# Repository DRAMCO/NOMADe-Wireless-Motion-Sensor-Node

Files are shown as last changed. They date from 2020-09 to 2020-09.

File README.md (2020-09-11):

# NOMADe - Wireless Motion Sensor Node
 Documentation about the wireless motion sensor node.

## Software
 This map contains the c/c++ and python code for both the sensor node and receiver.
 
## Hardware
 Here you can find the Eagle schematics and STL files.

## How to cite
```LaTex
@Misc{Interreg-NOMADe,
  author =   {J. Cappelle},
  title =    {{Wireless Motion Sensor Node}},
  howpublished  = {\url{https://github.com/DRAMCO/NOMADe-Wireless-Motion-Sensor-Node}},
  doi = {10.5281/zenodo.4024373}
}
```

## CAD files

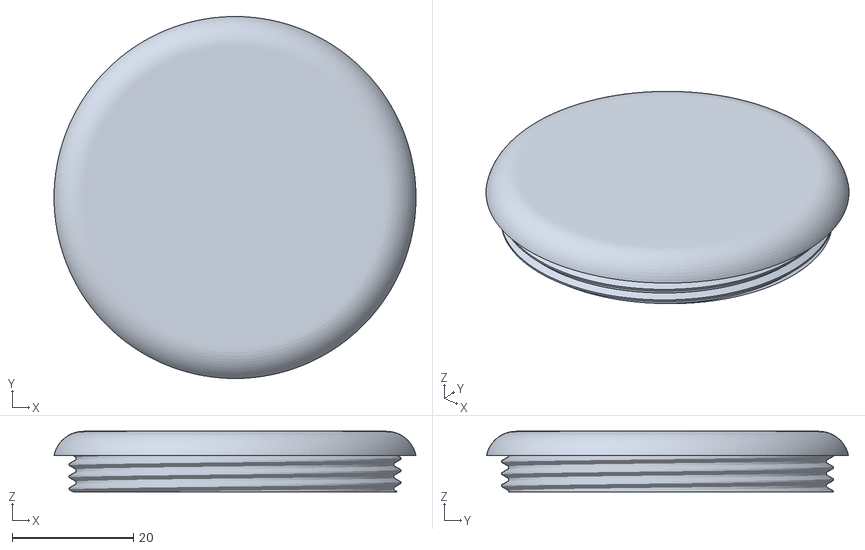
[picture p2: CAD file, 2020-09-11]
Hardware/top.stl
59.8 x 59.8 x 10.0

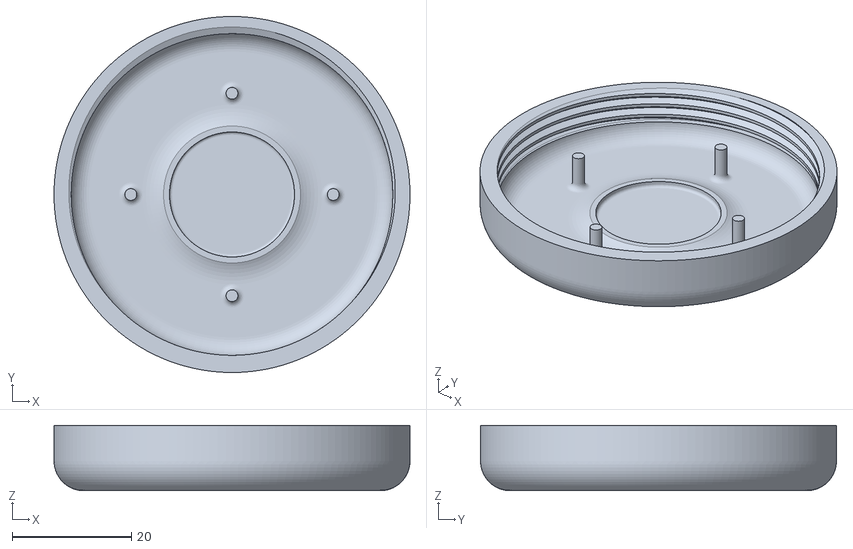
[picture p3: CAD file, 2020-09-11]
Hardware/bottom.stl
59.8 x 59.8 x 11.0

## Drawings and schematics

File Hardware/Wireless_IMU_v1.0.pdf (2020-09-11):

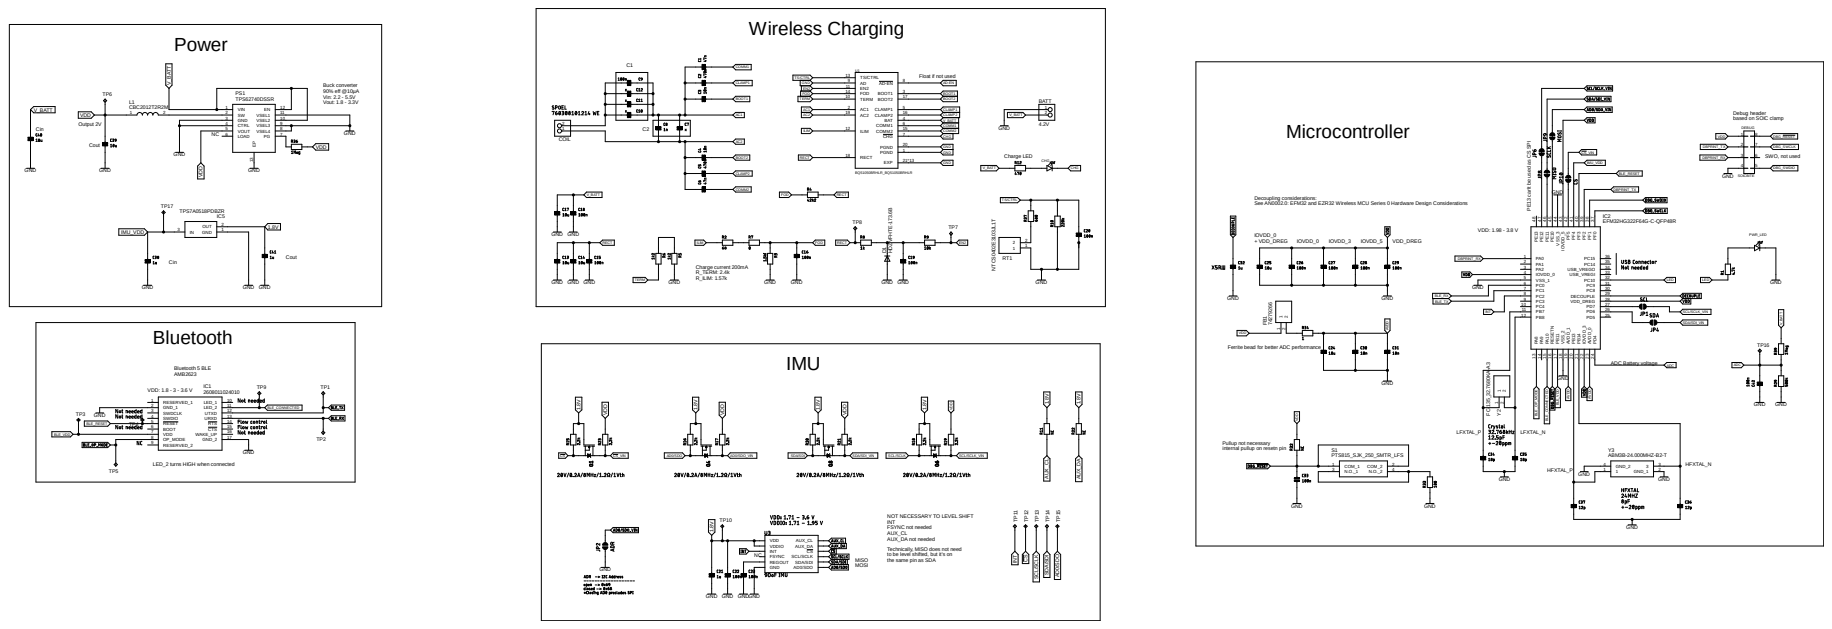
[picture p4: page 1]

Float if not used

Debug header
based on SOIC clamp

Decoupling considerations:
See AN0002.0: EFM32 and EZR32 Wireless MCU Series 0 Hardware Design Considerations

25 PE¹³ ⁴⁸ PE¹² ⁴⁷ PE¹¹ ⁴⁶ PE¹⁰ ⁴⁵ VSS_3 44 IOVDD_5 43 PF5 42 PF4 41 PF3 40 PF2 39 PF1 38 PF0 37

Ferrite bead for better ADC performance

Pullup not necessary
internal pullup on resetn pin

LED_2 turns HIGH when connected

NOT NECESSARY TO LEVEL SHIFT
INT
FSYNC not needed
AUX_CL
AUX_DA not needed
Technically, MISO does not need
to be level shifted, but it's on
the same pin as SDA

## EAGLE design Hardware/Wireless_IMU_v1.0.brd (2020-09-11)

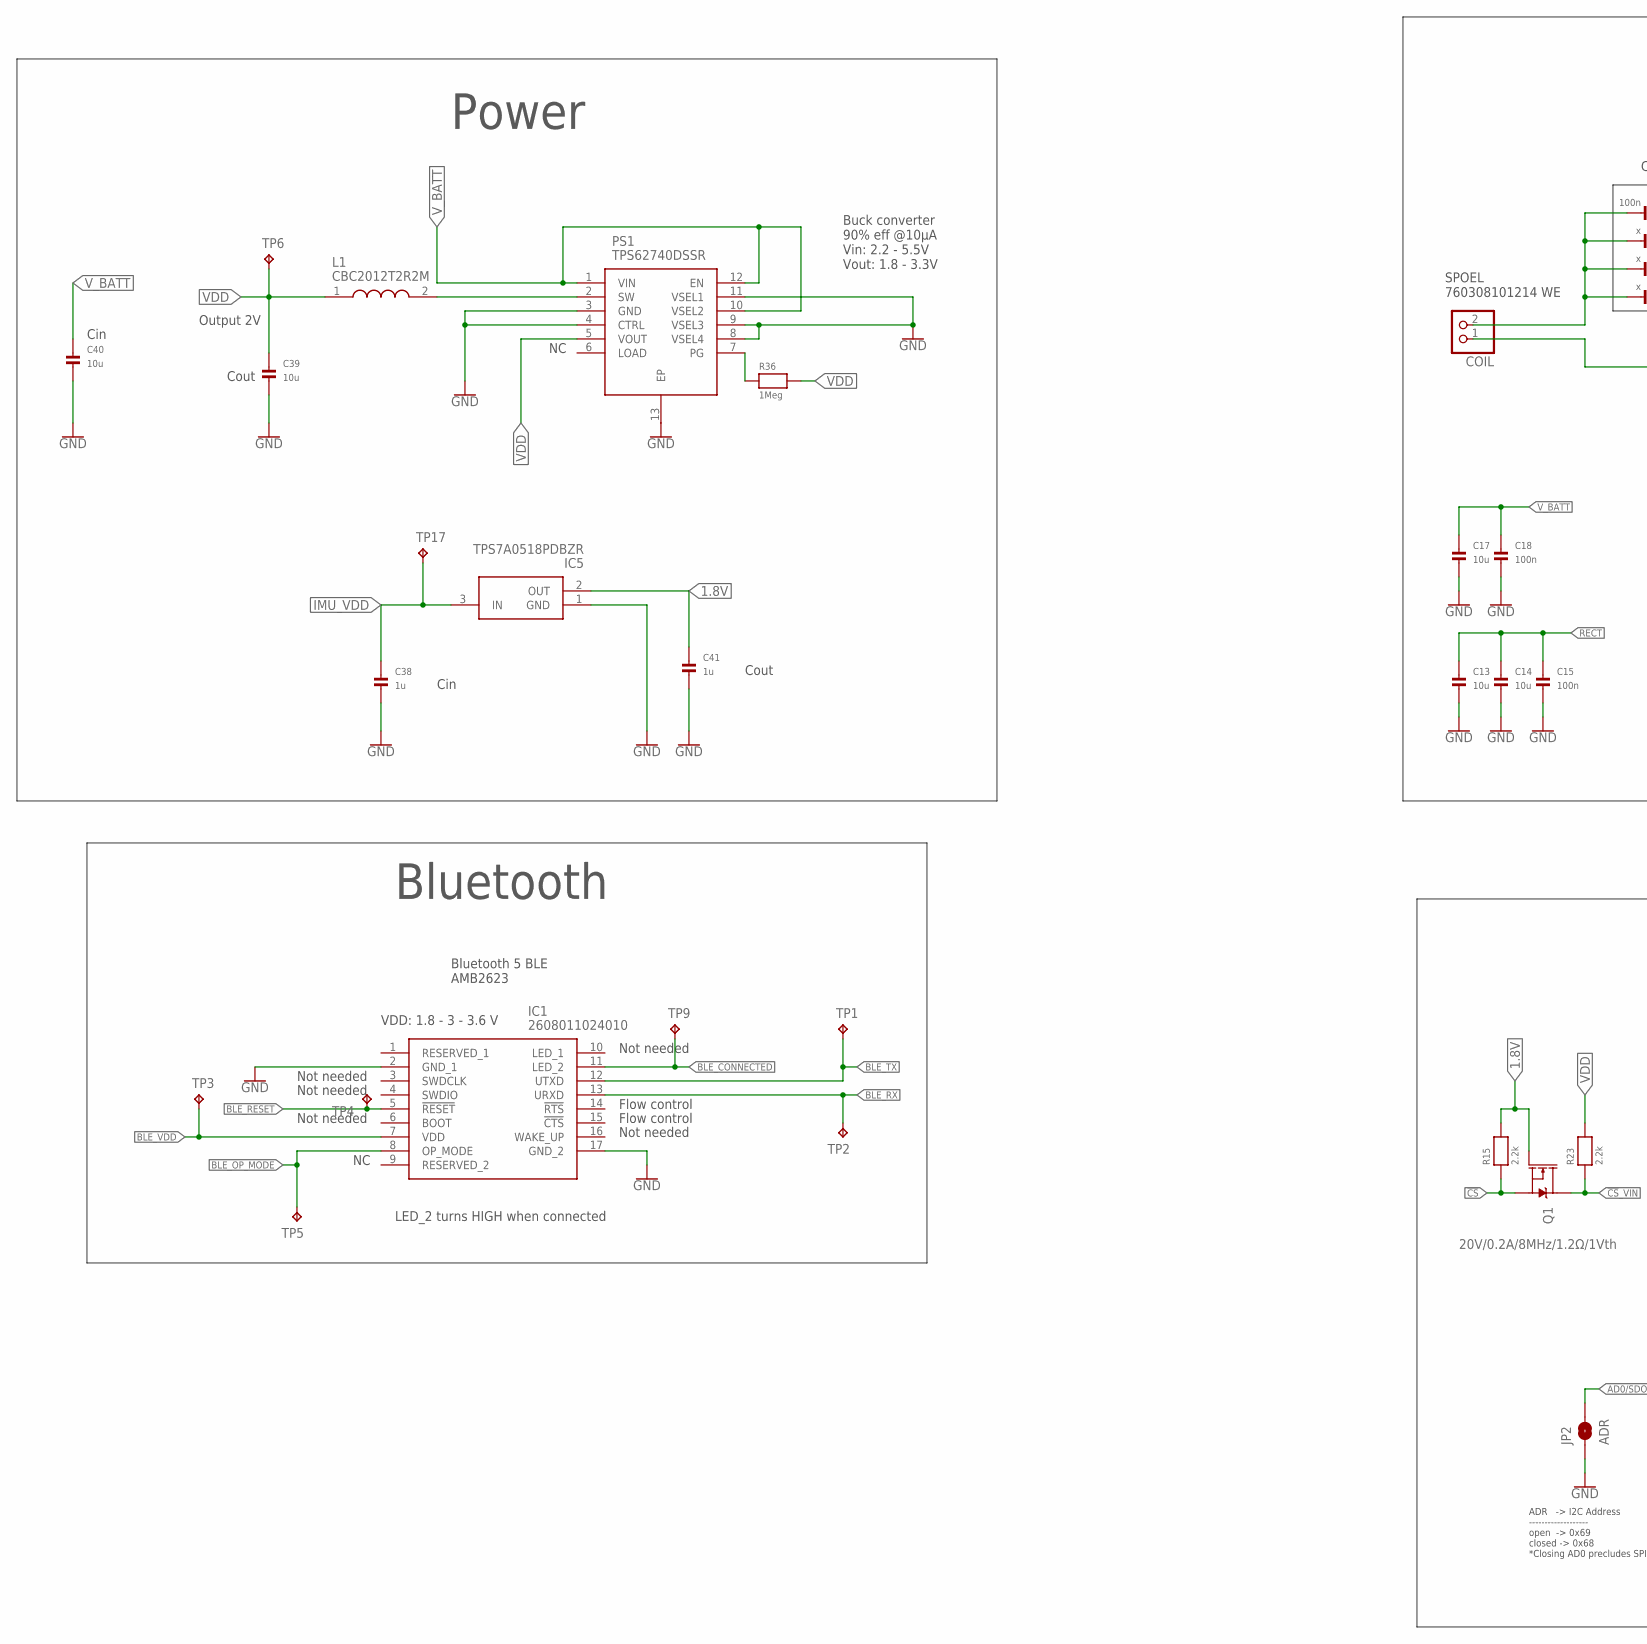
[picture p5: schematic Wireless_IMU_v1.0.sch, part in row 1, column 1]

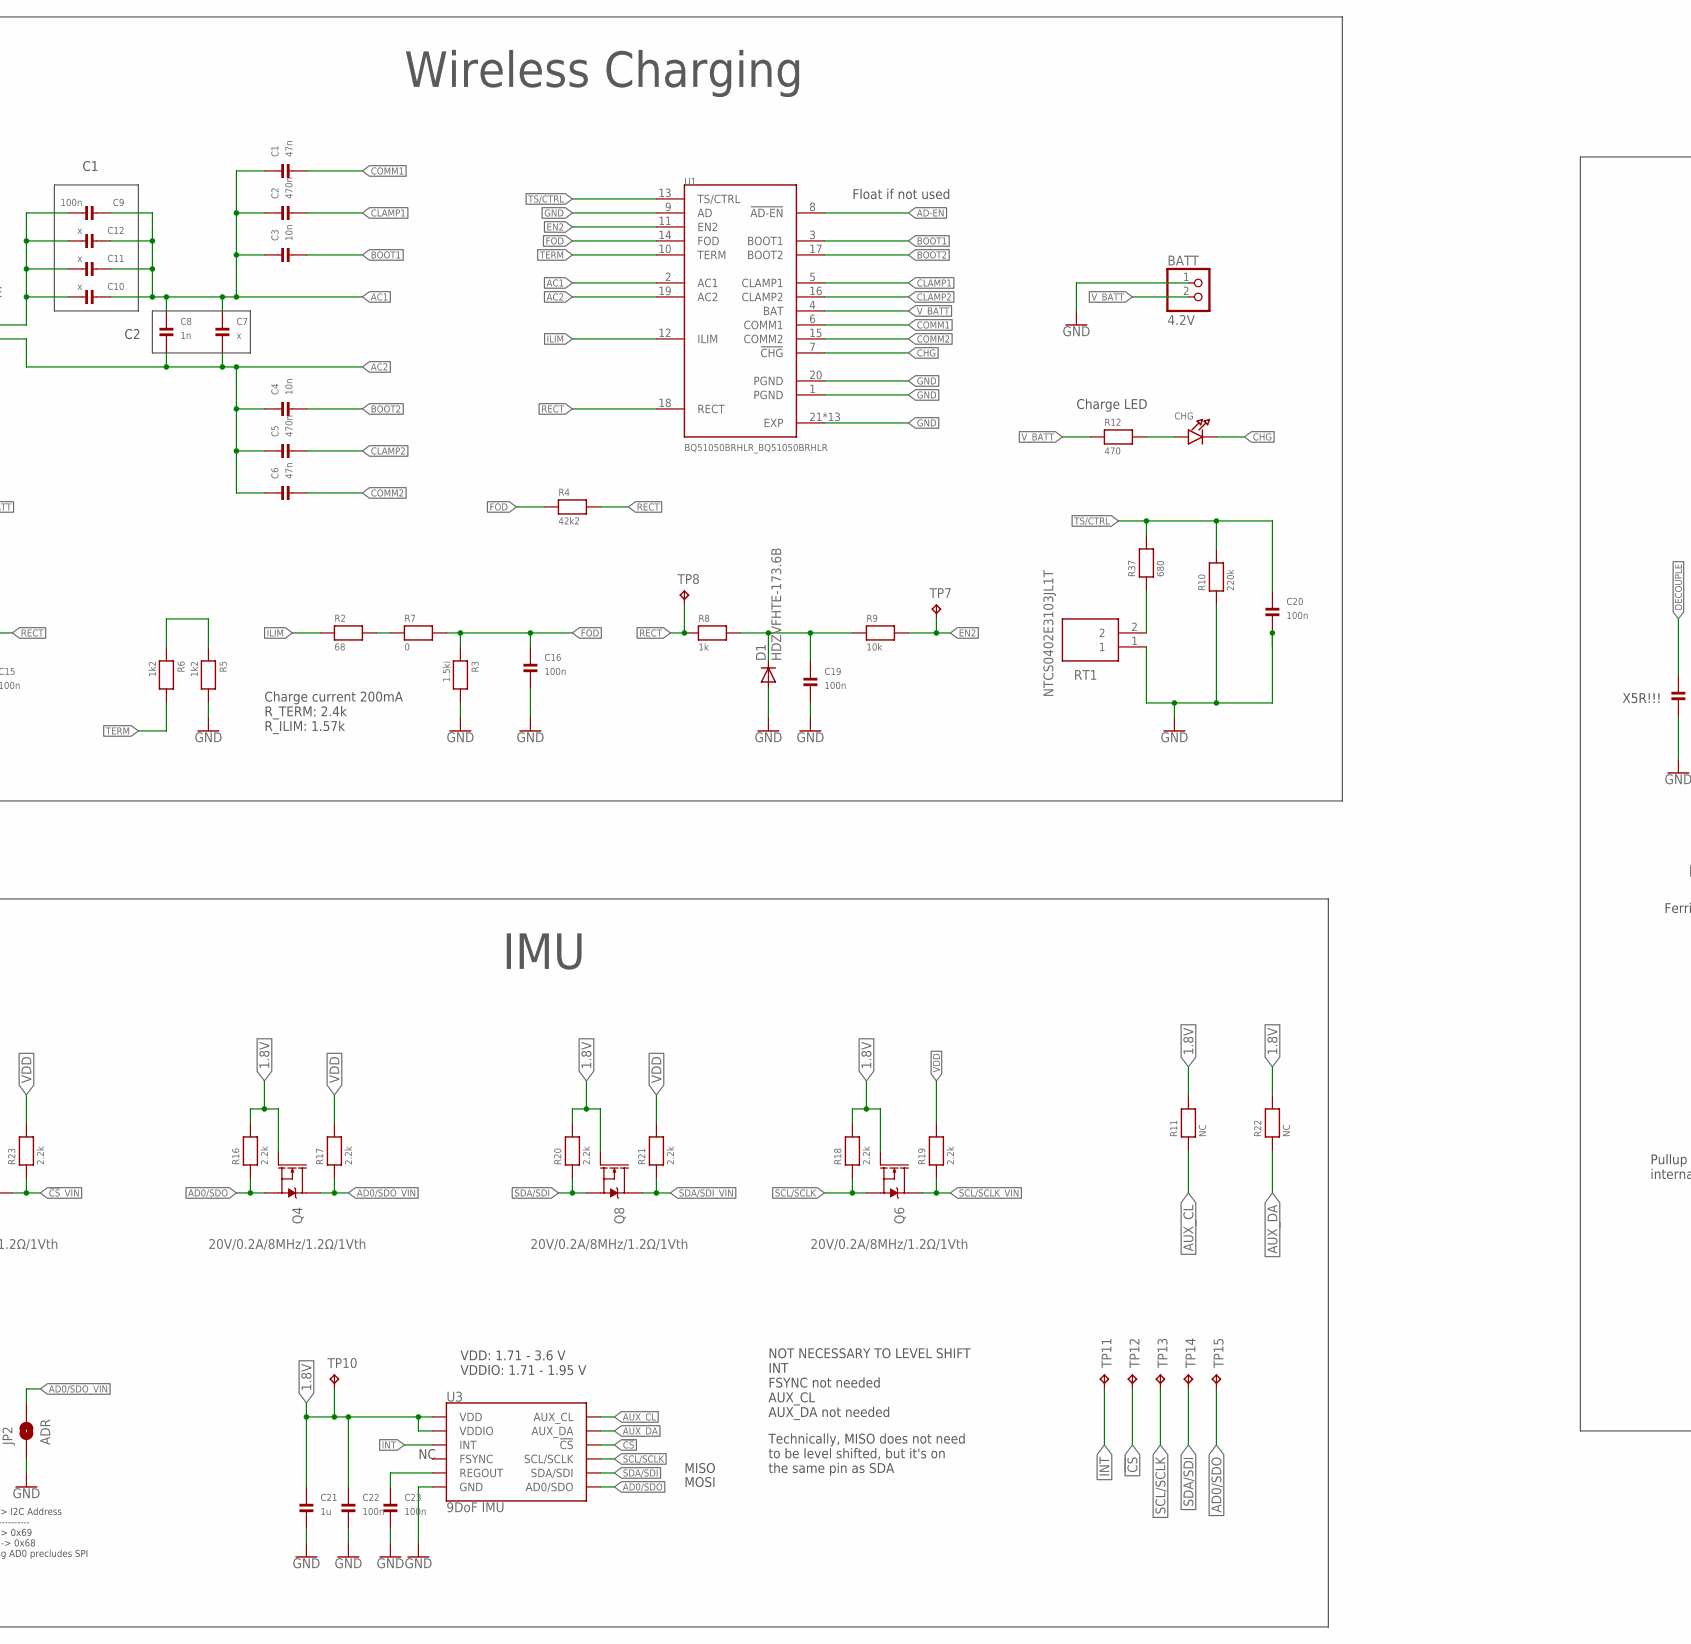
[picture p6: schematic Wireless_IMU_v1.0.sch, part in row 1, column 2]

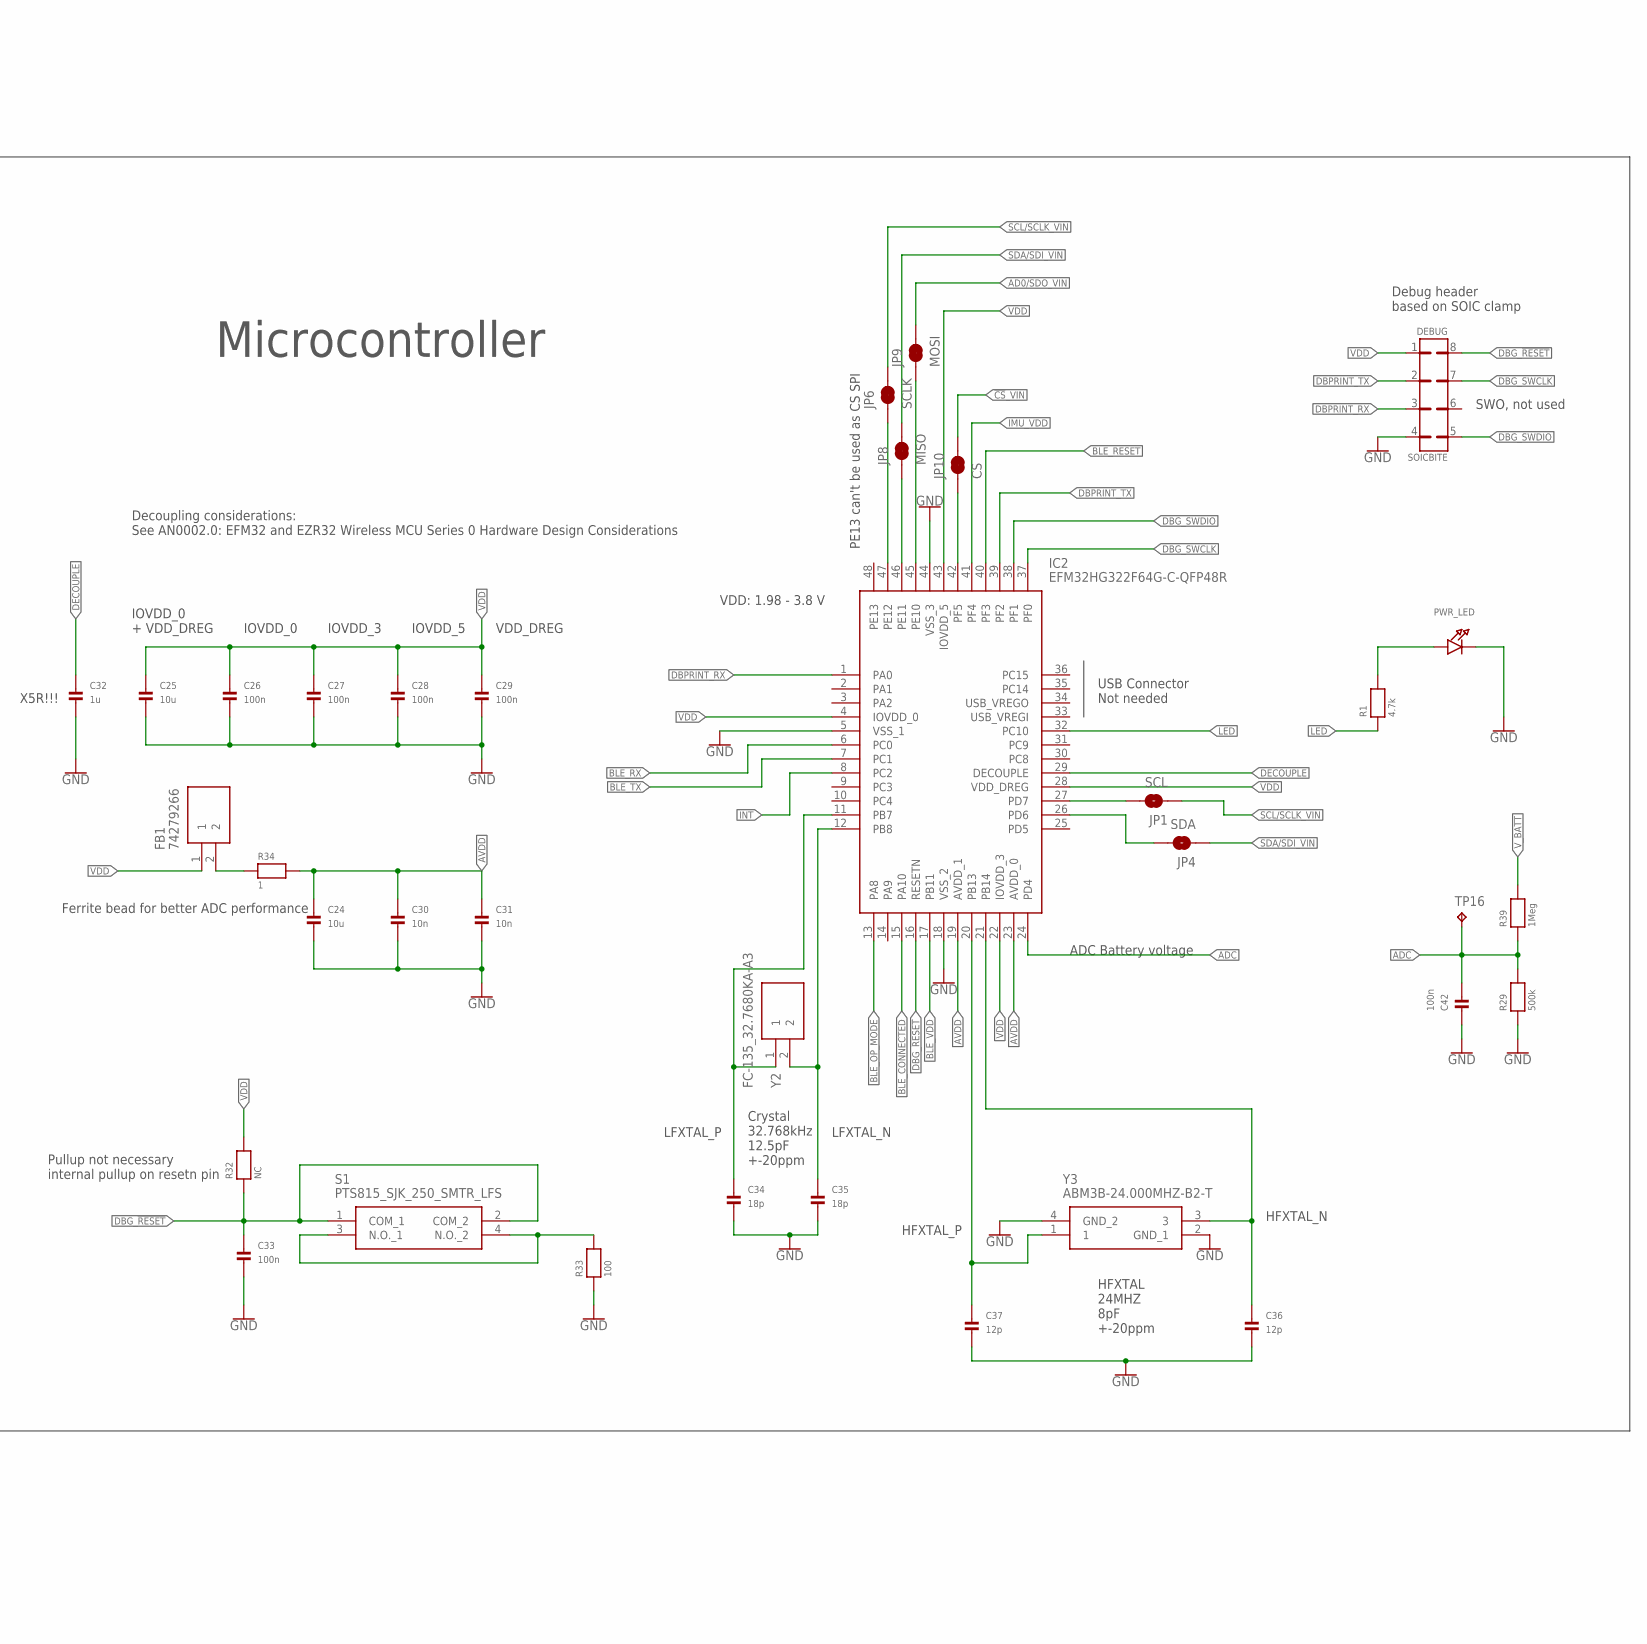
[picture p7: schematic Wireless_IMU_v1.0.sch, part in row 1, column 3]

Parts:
BATT: 4.2V; 1X02
C1, C6: 47n; 0603
C2, C5: 470n; 0603
C3, C4, C30, C31: 10n; 0603
C7, C10, C11, C12: x; 0603
C8: 1n; 0603
C9, C15, C16, C18, C19, C20, C22, C23, C26, C27, C28, C29, C33, C42: 100n; 0603
C13, C14, C17, C24, C25, C39, C40: 10u; 0603
C21, C32, C38, C41: 1u; 0603
C34, C35: 18p; 0603
C36, C37: 12p; 0603
CHG: LED0805; CHIPLED_0805
COIL: PINHD-1X2; 1X02
D1: HDZVFHTE-173.6B; SOD323-W
DEBUG: SOICBITE
FB1: 74279266; BEADC1608X100N
IC1: 2608011024010
IC2: EFM32HG322F64G-C-QFP48R; QFP50P900X900X120-48N
IC5: TPS7A0518PDBZR; SOT95P237X112-3N
JP1: SCL; SMT-JUMPER_2_NO_SILK
JP2: ADR; SMT-JUMPER_2_NO_SILK
JP4: SDA; SMT-JUMPER_2_NO_SILK
JP6: SCLK; SMT-JUMPER_2_NC_TRACE_SILK
JP8: MISO; SMT-JUMPER_2_NC_TRACE_SILK
JP9: MOSI; SMT-JUMPER_2_NC_TRACE_SILK
JP10: CS; SMT-JUMPER_2_NC_TRACE_SILK
L1: CBC2012T2R2M; INDC2012X145N
PS1: TPS62740DSSR; SON50P200X300X80-13N
PWR_LED: LED0805; CHIPLED_0805
Q1, Q4, Q6, Q8: 20V/0.2A/8MHz/1.2Ω/1Vth; SOT-416FL
R1: 4.7k; 0603
R2: 68; 0603
R3: 1.5ki; 0603
R4: 42k2; 0603
R5, R6: 1k2; 0603
R7: 0; 0603
R8: 1k; 0603
R9: 10k; 0603
R10: 220k; 0603
R11, R22, R32: NC; 0603
R12: 470; 0603
R15, R16, R17, R18, R19, R20, R21, R23: 2.2k; 0603
R29: 500k; 0603
R33: 100; 0603
R34: 1; 0603
R36, R39: 1Meg; 0603
R37: 680; 0603
RT1: NTCS0402E3103JL1T; CAPC1005X65N
S1: PTS815_SJK_250_SMTR_LFS; PTS815SJK250SMTRLFS
TP1, TP2, TP3, TP4, TP5, TP6, TP7, TP8, TP9, TP10, TP11, TP12, TP13, TP14, TP15, TP16, TP17: TPTP10R; TP10R
U1: BQ51050BRHLR_BQ51050BRHLR; BQ51050BRHLR_QFN50P450X350X100-21N
U3: 9DoF IMU; SPARKFUN-SENSORS_QFN24-3X3
Y2: FC-135_32.7680KA-A3; FC135327680KAAG0
Y3: ABM3B-24.000MHZ-B2-T; ABM3B8000MHZ101UT

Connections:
1.8V: C21.1, C22.1, C41.1, IC5.2 (OUT), Q1.1 (G), Q4.1 (G), Q6.1 (G), Q8.1 (G), R11.2, R15.2, R16.2, R18.2, R20.2, R22.2, TP10.TP, U3.8 (VDDIO), U3.13 (VDD)
!CS: Q1.2 (S), R15.1, TP12.TP, U3.22 (!CS)
!CS!_VIN: JP10.2, Q1.3 (D), R23.1
AC1: C1.1, C2.1, C3.1, C7.1, C8.1, C9.2, C10.2, C11.2, C12.2, U1.2 (AC1)
AC2: C4.1, C5.1, C6.1, C7.2, C8.2, COIL.1, U1.19 (AC2)
AC11: C9.1, C10.1, C11.1, C12.1, COIL.2
AD0/SDO: Q4.2 (S), R16.1, TP15.TP, U3.9 (AD0/SDO)
AD0/SDO_VIN: JP2.2, JP9.2, Q4.3 (D), R17.1
AD-EN: U1.8 (!AD-EN)
ADC: C42.1, IC2.24 (PD4), R29.2, R39.1, TP16.TP
AUX_CL: R11.1, U3.7 (AUX_CL)
AUX_DA: R22.1, U3.21 (AUX_DA)
AVDD: C24.1, C30.1, C31.1, IC2.19 (AVDD_1), IC2.23 (AVDD_0), R34.2
BLE_CONNECTED: IC1.11 (LED_2), IC2.15 (PA10), TP9.TP
BLE_OP_MODE: IC1.8 (OP_MODE), IC2.13 (PA8), TP5.TP
BLE_RESET: IC1.5 (!RESET), IC2.40 (PF3), TP4.TP
BLE_RX: IC1.13 (URXD), IC2.6 (PC0), TP2.TP
BLE_TX: IC1.12 (UTXD), IC2.7 (PC1), TP1.TP
BLE_VDD: IC1.7 (VDD), IC2.17 (PB11), TP3.TP
BOOT1: C3.2, U1.3 (BOOT1)
BOOT2: C4.2, U1.17 (BOOT2)
CHG: CHG.C, U1.7 (!CHG)
CLAMP1: C2.2, U1.5 (CLAMP1)
CLAMP2: C5.2, U1.16 (CLAMP2)
COMM1: C1.2, U1.6 (COMM1)
COMM2: C6.2, U1.15 (COMM2)
DBG_!RESET: C33.1, DEBUG.8, IC2.16 (RESETN), R32.1, S1.1 (COM_1), S1.2 (COM_2)
DBG_SWCLK: DEBUG.7, IC2.37 (PF0)
DBG_SWDIO: DEBUG.5, IC2.38 (PF1)
DBPRINT_RX: DEBUG.3, IC2.1 (PA0)
DBPRINT_TX: DEBUG.2, IC2.39 (PF2)
DECOUPLE: C32.1, IC2.29 (DECOUPLE)
EN2: R9.2, TP7.TP, U1.11 (EN2)
FOD: C16.1, R3.1, R4.1, R7.2, U1.14 (FOD)
GND: BATT.1, C13.2, C14.2, C15.2, C16.2, C17.2, C18.2, C19.2, C20.2, C21.2, C22.2, C23.2, C24.2, C25.2, C26.2, C27.2, C28.2, C29.2, C30.2, C31.2, C32.2, C33.2, C34.2, C35.2, C36.2, C37.2, C38.2, C39.2, C40.2, C41.2, C42.2, D1.A, DEBUG.4, IC1.2 (GND_1), IC1.17 (GND_2), IC2.5 (VSS_1), IC2.18 (VSS_2), IC2.44 (VSS_3), IC5.1 (GND), JP2.1, PS1.3 (GND), PS1.4 (CTRL), PS1.8 (VSEL4), PS1.9 (VSEL3), PS1.11 (VSEL1), PS1.13 (EP), PWR_LED.C, R3.2, R5.2, R10.1, R29.1, R33.1, RT1.1, U1.1 (PGND), U1.9 (AD), U1.20 (PGND), U1.21 (EXP), U1.22 (EXP), U1.23 (EXP), U1.24 (EXP), U1.25 (EXP), U1.26 (EXP), U1.27 (EXP), U1.28 (EXP), U1.29 (EXP), U1.30 (EXP), U1.31 (EXP), U1.32 (EXP), U1.33 (EXP), U3.18 (GND), U3.20 (GND), Y3.2 (GND_1), Y3.4 (GND_2)
ILIM: R2.1, U1.12 (ILIM)
IMU_VDD: C38.1, IC2.41 (PF4), IC5.3 (IN), TP17.TP
INT: IC2.8 (PC2), TP11.TP, U3.12 (INT)
LED: IC2.32 (PC10), R1.1
unnamed: IC2.27 (PD7), JP1.2
unnamed: R5.1, R6.1
unnamed: PWR_LED.A, R1.2
unnamed: R2.2, R7.1
unnamed: CHG.A, R12.2
unnamed: C19.1, D1.C, R8.2, R9.1
unnamed: IC2.26 (PD6), JP4.2
unnamed: IC2.47 (PE12), JP6.1
unnamed: C35.1, IC2.12 (PB8), Y2.2
unnamed: C23.1, U3.10 (REGOUT)
unnamed: IC2.46 (PE11), JP8.1
unnamed: IC2.45 (PE10), JP9.1
unnamed: C34.1, IC2.11 (PB7), Y2.1
unnamed: IC2.42 (PF5), JP10.1
unnamed: C37.1, IC2.20 (PB13), Y3.1
unnamed: C36.1, IC2.21 (PB14), Y3.3
unnamed: R33.2, S1.3 (N.O._1), S1.4 (N.O._2)
unnamed: FB1.2, R34.1
unnamed: R37.1, RT1.2
unnamed: L1.2, PS1.2 (SW)
unnamed: PS1.7 (PG), R36.1
RECT: C13.1, C14.1, C15.1, R4.2, R8.1, TP8.TP, U1.18 (RECT)
SCL/SCLK: Q6.2 (S), R18.1, TP13.TP, U3.23 (SCL/SCLK)
SCL/SCLK_VIN: JP1.1, JP6.2, Q6.3 (D), R19.1
SDA/SDI: Q8.2 (S), R20.1, TP14.TP, U3.24 (SDA/SDI)
SDA/SDI_VIN: JP4.1, JP8.2, Q8.3 (D), R21.1
TERM: R6.2, U1.10 (TERM)
TS/CTRL: C20.1, R10.2, R37.2, U1.13 (TS/CTRL)
VDD: C25.1, C26.1, C27.1, C28.1, C29.1, C39.1, DEBUG.1, FB1.1, IC2.4 (IOVDD_0), IC2.22 (IOVDD_3), IC2.28 (VDD_DREG), IC2.43 (IOVDD_5), L1.1, PS1.5 (VOUT), R17.2, R19.2, R21.2, R23.2, R32.2, R36.2, TP6.TP
V_BATT: BATT.2, C17.1, C18.1, C40.1, PS1.1 (VIN), PS1.10 (VSEL2), PS1.12 (EN), R12.1, R39.2, U1.4 (BAT)

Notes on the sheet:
Wireless Charging
Bluetooth
IMU
Microcontroller
VDD: 1.8 - 3 - 3.6 V
Bluetooth 5 BLE AMB2623
ADR -> I2C Address ------------------- open -> 0x69 closed -> 0x68 *Closing AD0 precludes SPI
SPOEL 760308101214 WE
VDD: 1.71 - 3.6 V VDDIO: 1.71 - 1.95 V
Not needed
Flow control
USB Connector Not needed
X5R!!!
Crystal 32.768kHz 12.5pF +-20ppm
HFXTAL 24MHZ 8pF +-20ppm
HFXTAL_P
HFXTAL_N
LFXTAL_P
LFXTAL_N
Ferrite bead for better ADC performance
IOVDD_0 + VDD_DREG
IOVDD_0
IOVDD_3
IOVDD_5
Decoupling considerations: See AN0002.0: EFM32 and EZR32 Wireless MCU Series 0 Hardware Design Considerations
Pullup not necessary internal pullup on resetn pin
Debug header based on SOIC clamp
Power
VDD: 1.98 - 3.8 V
Buck converter 90% eff @10µA Vin: 2.2 - 5.5V Vout: 1.8 - 3.3V
Output 2V
Cout
Cin
PE13 can't be used as CS SPI
NOT NECESSARY TO LEVEL SHIFT INT FSYNC not needed AUX_CL AUX_DA not needed
MISO
MOSI
Technically, MISO does not need to be level shifted, but it's on the same pin as SDA
ADC Battery voltage
VDD_DREG

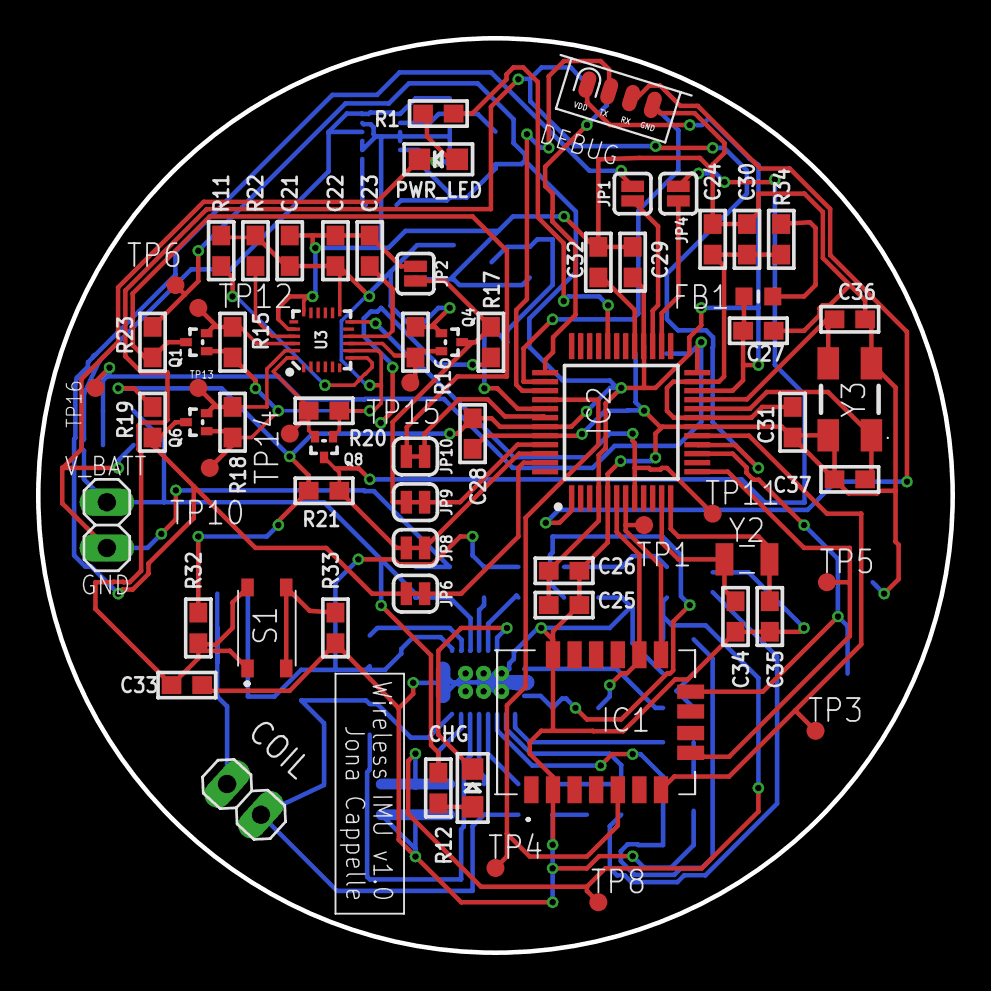
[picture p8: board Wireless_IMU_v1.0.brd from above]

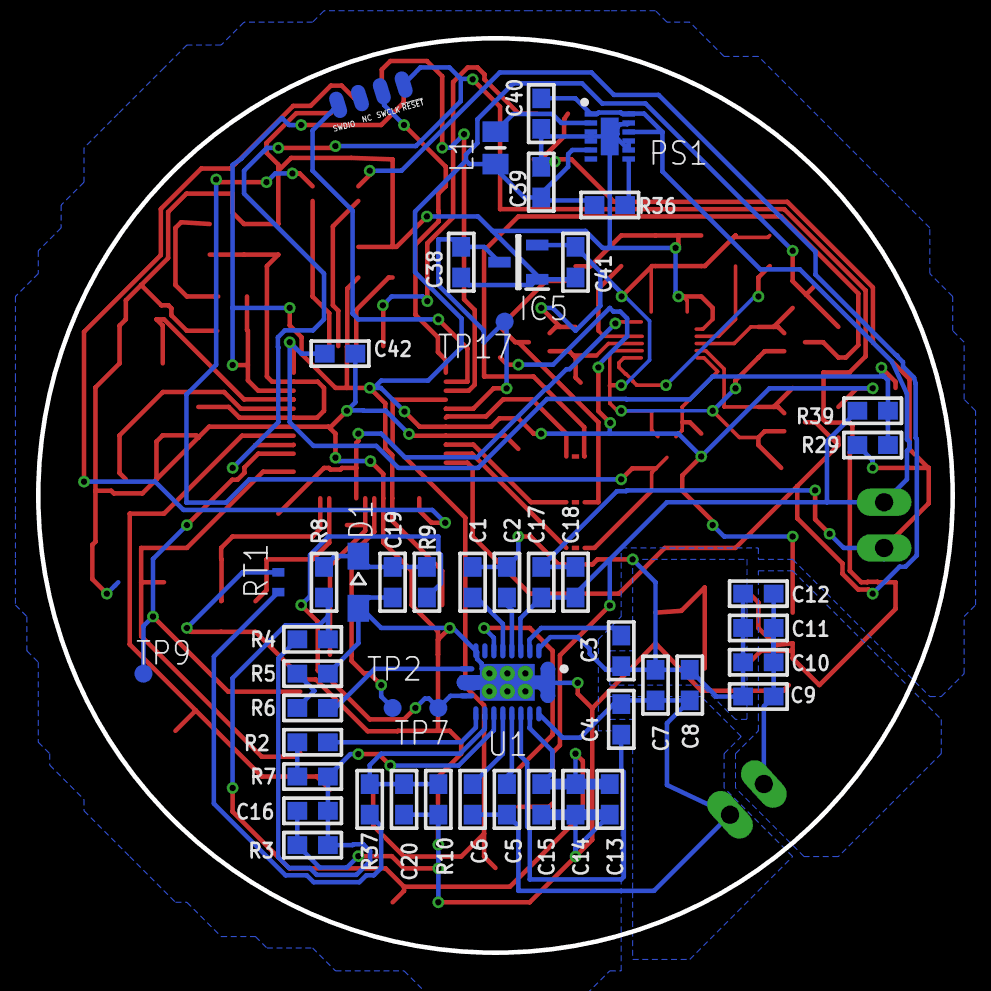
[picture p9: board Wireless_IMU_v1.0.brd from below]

Board: 2 copper layers, 50.8 x 50.8 mm, 116 parts (48 on the bottom side), 68 nets.

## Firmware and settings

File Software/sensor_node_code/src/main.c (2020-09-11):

/* NOMADe Design Sensor Node */
/* Made By Jona Cappelle */

/*************************************************/
/****                                     ********/
/******             MAIN FILE               ******/
/****                                     ********/
/*************************************************/

/***************************************************************************//**
 * @file main.c
 * @brief Code used in master thesis, MAIN FILE
 * @details Development of sensor node to use for threating NMSA
 * @version 1.0
 * @author Jona Cappelle
 * ******************************************************************************
 *
 * @section Versions
 *
 *
 *   @li v1.0: NOMADe wireless sensor node result V1.0
 *
 * ******************************************************************************
 *
 * @todo
 *   **Future improvements:**@n
 *     - Measurement of accuracy of sensor node against reference system
 *     - Enable remote calibration by receiving special packet from BLE
 *
 * ******************************************************************************
 *
 * @section License
 *
 *   **Copyright (C) 2020 - Jona Cappelle**
 *
 *
 ******************************************************************************/










/*
 * Measurement of time
 *
 * uint32_t start = millis();
 * uint32_t duration = millis() - start;
 *
 */

/* Include system libraries */
#include <adc.h>
#include "em_system.h"
#include "em_device.h"
#include "em_chip.h"
#include "em_cmu.h"
#include "em_emu.h"
#include "em_gpio.h"
#include "em_usart.h"
#include "em_rtc.h"
#include "em_adc.h"
//#include "em_wdog.h"
#include "rtcdriver.h"
#include "em_core.h"

/* Include home made libraries */
#include "debug_dbprint.h"
#include "delay.h"
#include "ICM20948.h"
#include "interrupt.h"
#include "ble.h"
#include "uart.h"
#include "timer.h"
#include "datatypes.h"
#include "util.h"

/* Need to make a separate file called "rtcdrv_config.h" and place:
 *
 * #define EMDRV_RTCDRV_WALLCLOCK_CONFIG
 * To enable clock functionality
 // */
#include "rtcdrv_config.h" // voor millis();

/* Separate file for Pins and Constants */
#include "pinout.h"

/* Needed to use uintx_t */
#include <stdint.h>
#include <stdbool.h>
//#include "stdio.h"

/* Communication */
#include "I2C.h"
//#include "em_i2c.h"
//#include "i2cspm.h"				/* I2C higher level library to easily setup and use I2C */

/* Sensor fusion */
#include "MadgwickAHRS.h"
#include "math.h"

/* LED's */
#include "bsp.h"

/* Energy profiles trace code */
#include "bsp_trace.h"

/*************************************************/
/*************************************************/

#define DIY				1							/**< Variable to change between pinout of sensor node and pinout of development board */

/* The use of switch - cases makes the code more user friendly */
static volatile APP_State_t appState;				/**< Struct to keep track of the appState */

/* Keep the measurement data */
MeasurementData_t data;								/**< Struct to store al the measured data and calibration values */

/* bool to check if bluetooth is connected */
bool bleConnected = false;							/**< Keep track of the state of the BLE module */
bool IMU_MEASURING = false;							/**< Keep track of the state of the IMU */
bool IDLE = false;									/**< Variable to keep track if the system is IDLE of the IDLE state, not used at the moment */
bool _sleep = false;								/**< Variable to fix some problems with IMU generating interrupt and thus waking up the system when trying to go to sleep */

uint8_t idle_count = 0;								/**< Seconds that the IMU is idle */
uint8_t ble_sec_not_connected = 0;					/**< 200 ms that the BLE is not connected */

uint32_t interruptStatus[1];						/**< Not used at the moment */

/* Timer for IMU idle checking */
RTCDRV_TimerID_t IMU_Idle_Timer;					/**< Timer used for checking variables every second */

/* Test pin to check frequency of execution */

bool helft = false;									/**< Not used at the moment */

uint8_t teller = 0;									/**< Not used at the moment */
uint8_t teller_accuracy = 0;						/**< Counter to keep track when to enter accuracy mode on Madgwick filter */

volatile float beta = 1.0f;							/**< Beta parameter of Madgwick filter */


/*************************************************/
/*************************************************/

/**************************************************************************//**
 * @brief
 *   Function called by RTC timer every second
 *
 * @details
 *	 Check batt
 *	 Check gyro idle
 *	 Check BLE connected
 *	 Dynamically set Madgwick beta parameter
 *
 *
 *****************************************************************************/
void CheckIMUidle( void )
{

	/* Read battery in percent */
	ADC_get_batt(data.batt);

	float mean_gyro = (uint8_t) ( data.ICM_20948_gyro[0] + data.ICM_20948_gyro[1] + data.ICM_20948_gyro[2] ) / 3;

	/* Add 1 sec to the count of idle seconds */
	if( mean_gyro < 0.1 )
	{
		idle_count++;
	}else{ /* If there is movement, reset idle seconds */
		idle_count = 0;
	}


	if( (idle_count > 60) || (ble_sec_not_connected > 5*5)) // 5sec * 75Hz
	{
		idle_count = 0;
		ble_sec_not_connected = 0;
		teller_accuracy = 0;
		beta = 1.0f;
		/* Dont't check idle state in sleep */
		RTCDRV_StopTimer( IMU_Idle_Timer );
		/* Stop generating interrupts */
		ICM_20948_interruptEnable(false, false);
		appState = SLEEP;
		_sleep = true;
	}
	// Reset timer is BLE is connected
	if(bleConnected)
	{
		ble_sec_not_connected = 0;
	}

/* For visual representation where in the code */
#if DIY == 0
	BSP_LedToggle(1);
#endif

	if(teller_accuracy < 10)
	{
		teller_accuracy++;
	}

	if(teller_accuracy >= 10)
	{
		beta = 0.05f;
	}

}

/**************************************************************************//**
 * @brief
 *   Function called by interrupt from IMU @50 Hz
 *
 * @details
 *	 Measure Gyro + Accel + Magn
 *	 Sensor fusion with Madgwick filter
 *	 Convert quaternions to Euler angles
 *	 Convert floats to uint8_t for transmission
 *	 Send data via UART to BLE module (interrupt based)
 *	 Toggle pin to check speed
 *
 * @note
 * 	 Max execution speed 75 Hz
 *
 *
 *
 *****************************************************************************/
void measure_send( void )
{

	/* Check connection */
#if DEBUG_DBPRINT == 0 /* DEBUG_DBPRINT */
	BLE_check_connect();
	if (!bleConnected)
	{
		ble_sec_not_connected++;
		BLE_power(true);
		delay(200);
		BLE_connect();
	}

#endif /* DEBUG_DBPRINT */

	/* Read all sensors */
	ICM_20948_gyroDataRead(data.ICM_20948_gyro);
	ICM_20948_accelDataRead(data.ICM_20948_accel);
	ICM_20948_magDataRead(data.ICM_20948_magn);

	// TODO: embedded ICM_20948_magn_to_angle( ICM_20948_magn, ICM_20948_magn_angle );

//	uint32_t start = millis();

	/* Sensor fusion */
	MadgwickAHRSupdate(data.ICM_20948_gyro[0] * M_PI / 180.0f,
			data.ICM_20948_gyro[1] * M_PI / 180.0f,
			data.ICM_20948_gyro[2] * M_PI / 180.0f,
			data.ICM_20948_accel[0], data.ICM_20948_accel[1],
			data.ICM_20948_accel[2], data.ICM_20948_magn[0], data.ICM_20948_magn[1], data.ICM_20948_magn[2]);
	QuaternionsToEulerAngles(data.ICM_20948_euler_angles);



//	uint32_t duration = millis() - start;

	/* Convert float's to uint8_t arrays for transmission over BLE */
	float_to_uint8_t_x3(data.ICM_20948_euler_angles,
			data.BLE_euler_angles);

//	helft = !helft;


#if DEBUG_DBPRINT == 0 /* DEBUG_DBPRINT */
//	if(helft == 1)
//	{

//	if(teller < 3)
//	{
	BLE_sendData(data.BLE_euler_angles, data.batt, 13, data.BLE_data);
	/* Test frequency */
	GPIO_PinOutSet(gpioPortE, 11);
	GPIO_PinOutClear(gpioPortE, 11);
//	}else{
//		teller = 0;
//	}
//	teller++;


//	}
#endif /* DEBUG_DBPRINT */

#if DIY == 0
	BSP_LedToggle(0);
#endif


}


/**************************************************************************//**
 * @brief
 *   Main function
 *
 * @details
 *	State diagram
 *	BATT_READ and CALLIBRATE will never be reached
 *	Future update: calibrate when receiving special BLE packet
 *
 *
 *****************************************************************************/
int main(void)
{

	/* Start with initialization */
	appState = INIT;

	/* Infinite loop */
	while (1)
	{
		switch (appState)
		{
		/***************************/
		case SYS_IDLE:
		{
			/* Wait in EM2 */
//			EMU_EnterEM2(true);

		}
			break;
		/***************************/
		case INIT:
		{
			/* Chip errata */
			CHIP_Init();


			/* ENABLE CODE CORRELATION --  uses SWO */
			/* If first word of user data page is non-zero, enable eA Profiler trace */
//			BSP_TraceProfilerSetup();

			/* FULL SPEED */
			CMU_ClockSelectSet(cmuClock_HF, cmuSelect_HFXO);
//			CMU_OscillatorEnable(cmuOsc_HFRCO, false, false);

			CMU_ClockEnable(cmuClock_HFPER, true);
			CMU_ClockEnable(cmuClock_GPIO, true);

			/* Set output pin to check frequency of execution */

			GPIO_PinModeSet(gpioPortE, 11, gpioModePushPull, 0);

#if DIY == 1
			GPIO_PinModeSet(LED_PORT, LED_PIN, gpioModePushPull, 1);
			delay(1000);
			GPIO_PinModeSet(LED_PORT, LED_PIN, gpioModeDisabled, 0);

			blink(3);
#endif

			/* Leds on development board */
#if DIY == 0
			BSP_LedsInit();
#endif

			/* Setup printing to virtual COM port, w */
#if DEBUG_DBPRINT == 1 /* DEBUG_DBPRINT */
			dbprint_INIT(USART1, 4, true, false);
#endif /* DEBUG_DBPRINT */

			/* Timer init */
			RTCDRV_Init();
			RTCDRV_AllocateTimer(&IMU_Idle_Timer);


			/* Initialize ICM_20948 + SPI interface */
			ICM_20948_Init();
			//ICM_20948_Init_SPI();

			/* Initialize GPIO interrupts on port C 2 */
			initGPIO_interrupt();

			/* Initialize ADC to read battery voltage */
			initADC();
//			ADC_get_batt(data.batt);



#if DEBUG_DBPRINT == 1 /* DEBUG_DBPRINT */
			dbprintln("INIT");
#endif /* DEBUG_DBPRINT */

			/* Bluetooth */
#if DEBUG_DBPRINT == 0 /* DEBUG_DBPRINT */
			BLE_Init();
#endif /* DEBUG_DBPRINT */

			delay(200);
			/* Set output power */
//			BLE_set_output_power(BLE_OUTPUT_POWER_0DB);
//			delay(100);

			// TODO Temporary
			/* Check connection */
#if DEBUG_DBPRINT == 0 /* DEBUG_DBPRINT */
			BLE_check_connect();
			if (!bleConnected)
			{
				BLE_power(true);
				delay(1000);
				BLE_connect();
			}
#endif /* DEBUG_DBPRINT */

			/* Set interrupt to trigger every 100ms when the data is ready */
			IMU_MEASURING = true;
			ICM_20948_interruptEnable(true, false);

			/* Fancy LED's */
#if DIY == 0
			for(uint8_t i=0; i<8; i++)
			{
				BSP_LedSet(0);
				BSP_LedSet(1);
				delay(100);
				BSP_LedClear(0);
				BSP_LedClear(1);
				delay(100);
			}
#endif

			/* Timer for checking if IMU is idle */
			  RTCDRV_StartTimer( IMU_Idle_Timer, rtcdrvTimerTypePeriodic, 2000, (RTCDRV_Callback_t)CheckIMUidle, NULL);



			appState = SYS_IDLE;


		}
			break;
			/***************************/
		case SENSORS_READ:
		{

#if DEBUG_DBPRINTs == 1 /* DEBUG_DBPRINT */
			dbprintln("SENSORS_READ");
#endif /* DEBUG_DBPRINT */

			measure_send();

#if DEBUG_DBPRINTs == 1 /* DEBUG_DBPRINT */
			dbprintInt((int) ( data.ICM_20948_gyro[0]*100) );
			dbprint(",");
			dbprintInt((int) (data.ICM_20948_gyro[1] *100) );
			dbprint(",");
			dbprintInt((int) (data.ICM_20948_gyro[2] *100) );
			dbprint(",");
			dbprintInt((int) ( data.ICM_20948_accel[0]*100) );
			dbprint(",");
			dbprintInt((int) (data.ICM_20948_accel[1] *100) );
			dbprint(",");
			dbprintlnInt((int) (data.ICM_20948_accel[2] *100) );
#endif /* DEBUG_DBPRINT */

#if DEBUG_DBPRINTs == 1 /* DEBUG_DBPRINT */
			//dbprint("	roll: ");
			dbprintInt((int) (ICM_20948_euler_angles[0] *100) );
			//dbprint("	pitch: ");
			dbprint("\t");
			dbprintInt((int) (ICM_20948_euler_angles[1] *100) );
			//dbprint("	yaw: ");
			dbprint("\t");
			dbprintlnInt((int) (ICM_20948_euler_angles[2] *100) );
#endif /* DEBUG_DBPRINT */

#if DEBUG_DBPRINTs == 1 /* DEBUG_DBPRINT */
			dbprintInt((int) ICM_20948_magn[0] );
			dbprint(",");
			dbprintInt((int) ICM_20948_magn[1] );
			dbprint(",");
			dbprintlnInt((int) ICM_20948_magn[2] );
#endif /* DEBUG_DBPRINT */


			/* If imu is idle, give it the chance to go to sleep */
			if(!_sleep)
			{
				appState = SYS_IDLE;
			}
		}
			break;
			/***************************/
		case BATT_READ:
		{
			ADC_Batt_Read();
			ADC_get_batt(data.batt);

#if DEBUG_DBPRINT == 1 /* DEBUG_DBPRINT */
			dbprintln("BATT_READ");
#endif /* DEBUG_DBPRINT */

			appState = SYS_IDLE;
		}
			break;
			/***************************/
		case SLEEP:
		{
			//RTCDRV_StartTimer( IMU_Idle_Timer, rtcdrvTimerTypeOneshot, 2000, test, NULL);

			RTCDRV_StopTimer( IMU_Idle_Timer );
			RTCDRV_DeInit();

			BLE_disconnect();
			delay(100);
			BLE_power( false);
			BLE_rxtx_enable( false );

			bleConnected = false;

			CMU_ClockEnable(cmuClock_ADC0, false);
//			GPIO_PinModeSet(gpioPortD, 4, gpioModeDisabled, 0);

			GPIO_PinModeSet(gpioPortE, 11, gpioModeDisabled, 0);


			/* Shut down magnetometer */
		    ICM_20948_set_mag_mode(AK09916_BIT_MODE_POWER_DOWN);
		    delay(100);

		    uint8_t temp1[8];
			ICM_20948_read_mag_register(0x31, 1, temp1);
			/* Update data by reading through till ST2 register */
			ICM_20948_read_mag_register(0x11, 8, temp1);


			/* Wake on motion: 50 mg's (0.05 G) */
			ICM_20948_wakeOnMotionITEnable(true, 20, 2.2);
//			ICM_20948_sleepModeEnable(true);
			delay(400);

			IIC_Enable(false);


			/* Disable Systicks before going to sleep */
			EMU_EnterEM2(true);


			///////////////////////////////////////////
			/* When waking up, initialize everything */
			///////////////////////////////////////////

			CMU_ClockSelectSet(cmuClock_HF, cmuSelect_HFXO);

			IIC_Enable(true);
			BLE_power(true);
			BLE_rxtx_enable( true );
			CMU_ClockEnable(cmuClock_ADC0, true);

			_sleep = false;

			/* Setup IMU */
			ICM_20948_lowPowerModeEnter(false, false, false);
			ICM_20948_Init2();


			/* Timer for checking if IMU is idle */
			RTCDRV_Init();
			RTCDRV_AllocateTimer(&IMU_Idle_Timer);
			RTCDRV_StartTimer( IMU_Idle_Timer, rtcdrvTimerTypePeriodic, 2000, (RTCDRV_Callback_t)CheckIMUidle, NULL);

			/* Set interrupt to trigger every 100ms when the data is ready */
			IMU_MEASURING = true;
			ICM_20948_interruptEnable(true, false);

			GPIO_PinModeSet(gpioPortE, 11, gpioModePushPull, 0);

			appState = SYS_IDLE;

#if DEBUG_DBPRINT == 1 /* DEBUG_DBPRINT */
			dbprintln("SLEEP");
#endif /* DEBUG_DBPRINT */
		}
			break;
			/***************************/
		case CALLIBRATE:
		{
#if DEBUG_DBPRINT == 1 /* DEBUG_DBPRINT */
			dbprintln("CALLIBRATE");
#endif /* DEBUG_DBPRINT */

			ICM_20948_accelGyroCalibrate(data.accelCal, data.gyroCal);
			ICM_20948_calibrate_mag(data.magOffset, data.magScale);

			appState = SYS_IDLE;
		}
			break;
			/***************************/
		} //switch

	} //while
} //main








/**************************************************************************//**
 * @brief GPIO Even IRQ for pushbuttons on even-numbered pins
 *****************************************************************************/
void GPIO_EVEN_IRQHandler(void)
{
	// Clear all even pin interrupt flags
	GPIO_IntClear(0x5555);
#if DEBUG_DBPRINTs == 1 /* DEBUG_DBPRINT */
	dbprint("Interrupt fired! 1");
#endif /* DEBUG_DBPRINT */

//	measure_send();

//	ICM_20948_interruptStatusRead(interruptStatus);
//
//	/* AND with mask to check only bit 4 of byte 1 */
//	if( (interruptStatus[0] & 8) == 8 ) /* If interrupt is bit WOM interrupt */
//	{
//		appState = SLEEP;
//	}else{

	/* If sensor is not trying to sleep, read sensors
	 * Otherwise bug when trying to sleep but still last interrupts occurring, sensor won't go to sleep
	 */
	if(appState != SLEEP)
	{
		appState = SENSORS_READ;
	}


//	}
}

/**************************************************************************//**
 * @brief GPIO Odd IRQ for pushbuttons on odd-numbered pins
 *****************************************************************************/
void GPIO_ODD_IRQHandler(void)
{
	// Clear all odd pin interrupt flags
	GPIO_IntClear(0xAAAA);

#if DEBUG_DBPRINTs == 1 /* DEBUG_DBPRINT */
	dbprint("Interrupt fired! 2");
#endif /* DEBUG_DBPRINT */

//	appState = SENSORS_READ;
}

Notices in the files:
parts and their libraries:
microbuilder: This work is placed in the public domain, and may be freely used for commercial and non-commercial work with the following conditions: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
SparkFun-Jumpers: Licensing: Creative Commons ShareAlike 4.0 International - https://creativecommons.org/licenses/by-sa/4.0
